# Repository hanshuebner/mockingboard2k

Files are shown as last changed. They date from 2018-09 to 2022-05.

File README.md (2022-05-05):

# mockingboard2k - Mockingboard compatible Apple II sound card

This Mockingboard clone uses SMD parts for all modern components.  The KiCAD
project was cloned from the Apple II 32-GPIO Card by Scott Alfter.

[Schematic](mockingboard2k.pdf)

Please make sure that you're using 6522A VIAs.  6522 chips often don't work
with the Phi2 generation circuit that is present on this board.

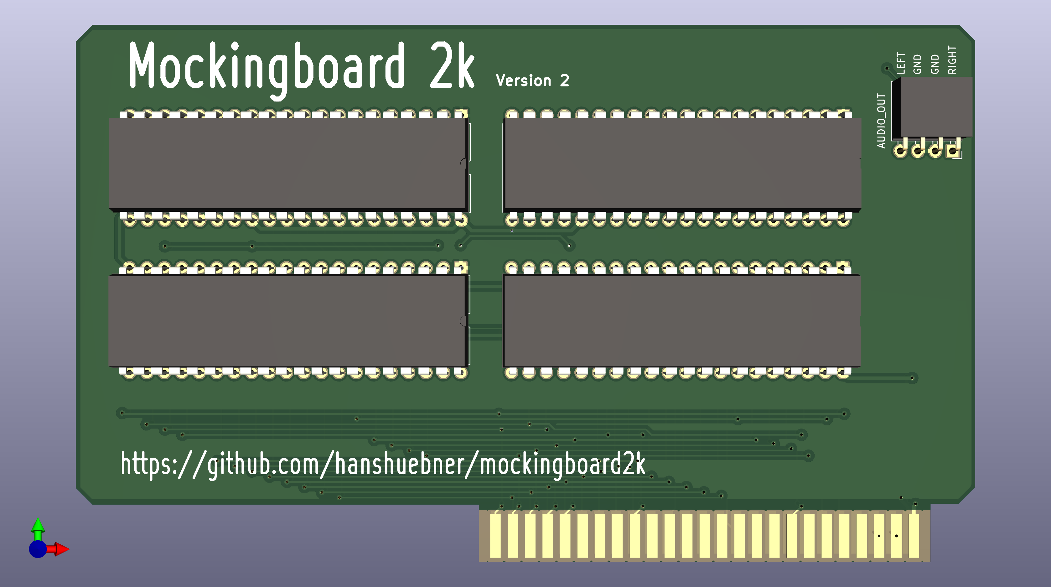
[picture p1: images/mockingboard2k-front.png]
PCB front PCB Front

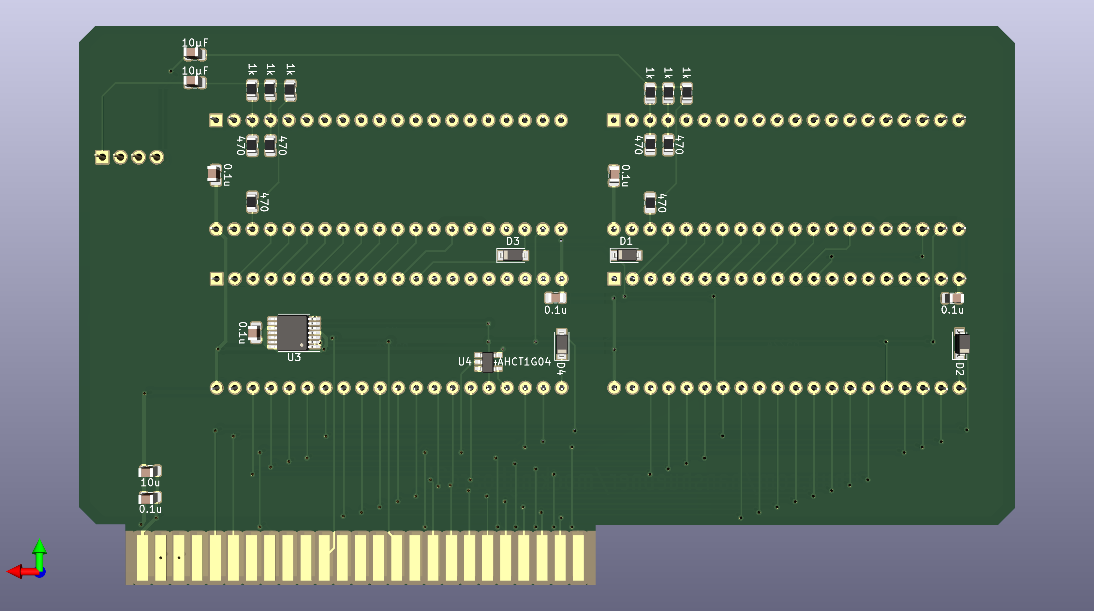
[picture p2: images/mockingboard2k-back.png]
PCB back PCB Back


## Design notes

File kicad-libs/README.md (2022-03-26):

KiCAD Library
=============

Components needed for my projects go here.  I'm starting with the proper
ANSI symbols for things like capacitors and resistors because KiCAD doesn't
provide them in its standard libraries.  Stuff needed for Apple II-related
projects is up next.

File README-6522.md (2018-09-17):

Apple II Dual-6522 GPIO Card
============================

This is a fairly straightforward implementation of a GPIO interface for the
Apple II, based on a pair of 6522 VIAs.  It is an extension of a design
published in c't Magazine in 1985, with the control lines on each 6522 also
brought out to header pins, the data bus buffered with a 74LS245, and the
ɸ2 signal needed by the 6522s generated by a pair of flip-flops in a 74LS74
in accordance with a technote published by Apple on the subject.  Most
components are surface-mount to reduce needed board area, though the 6522s
were kept in DIP form to allow use of either NOS (new old stock) 6522s from
whatever suppliers or the currently available WDC W65C22S.

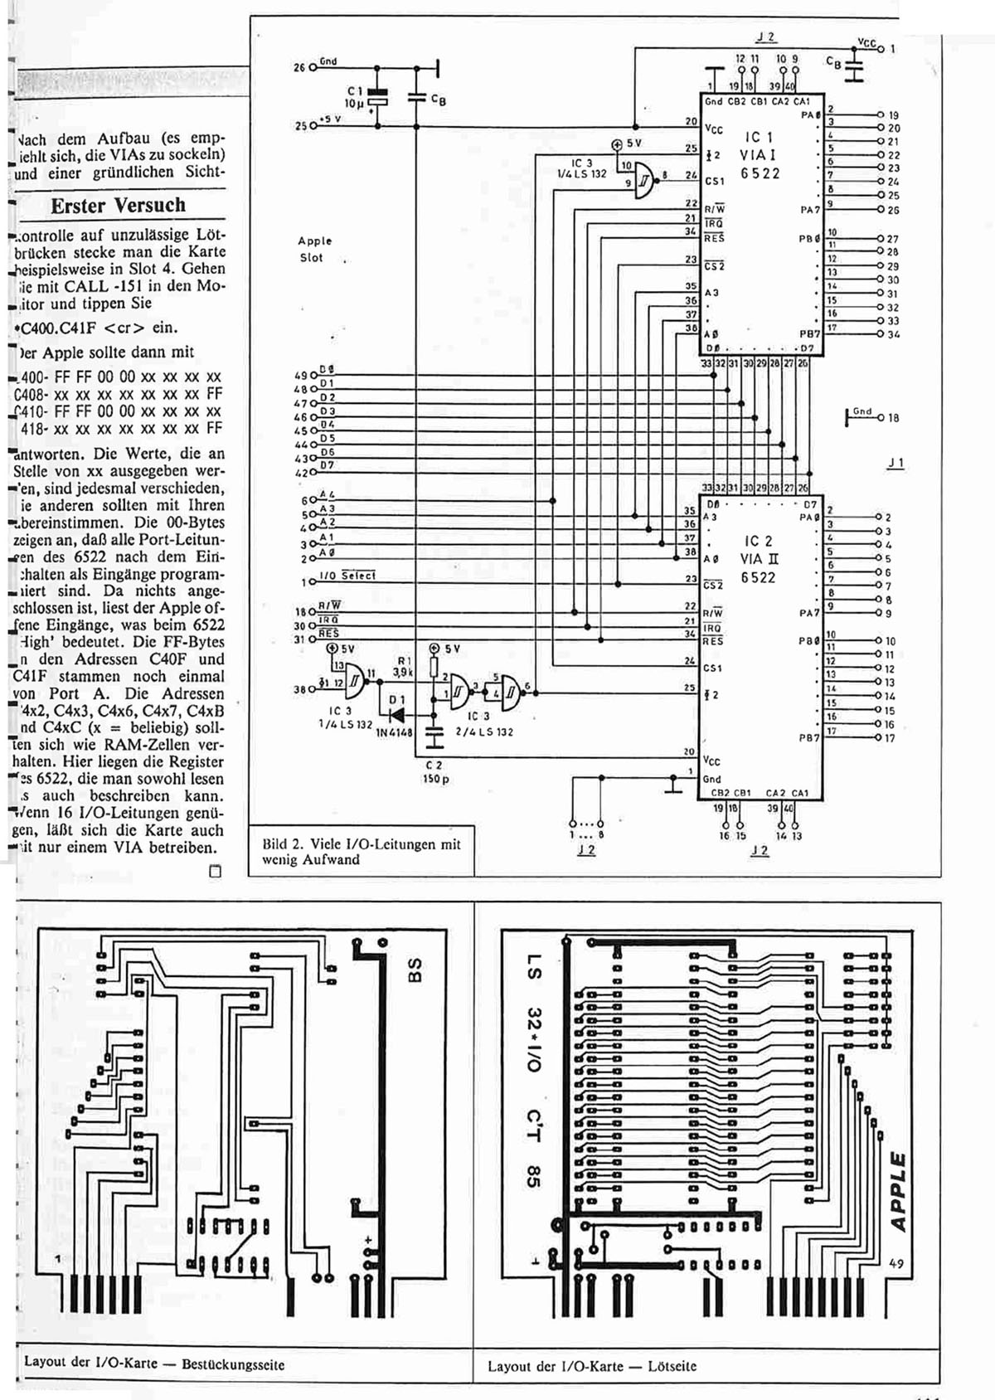
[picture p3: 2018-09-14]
docs/Apple2xVIA6522p2.jpg

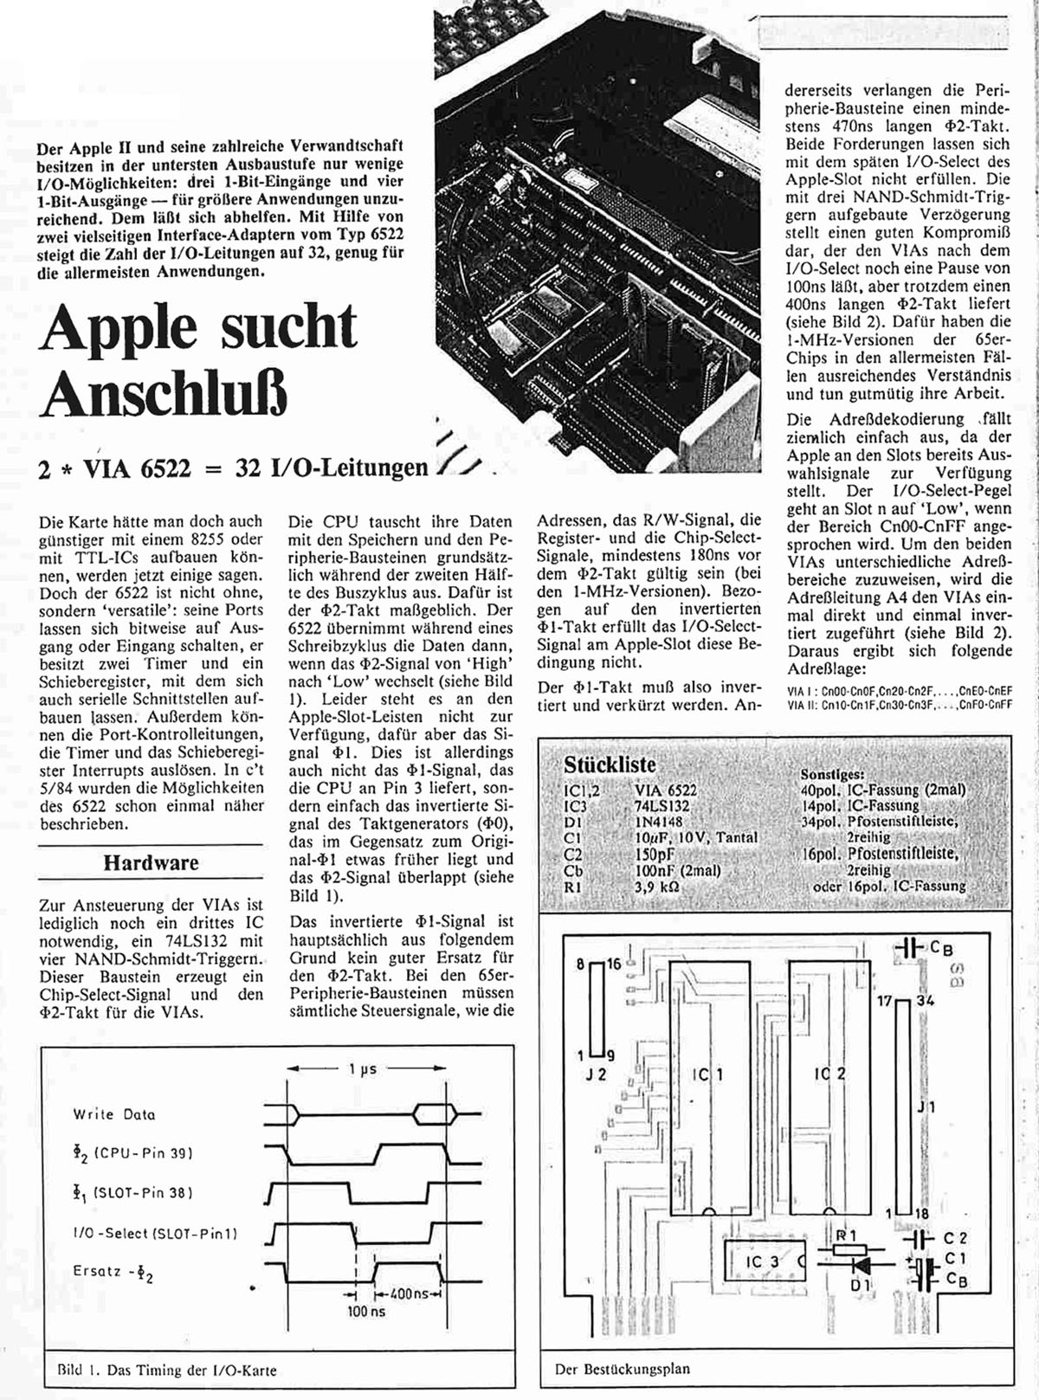
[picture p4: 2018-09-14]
docs/Apple2xVIA6522p1.jpg

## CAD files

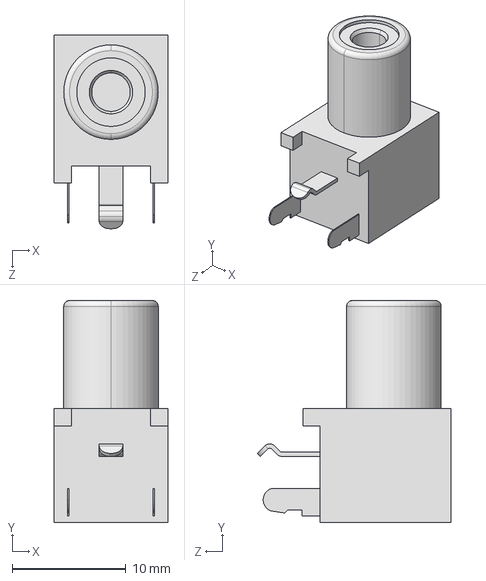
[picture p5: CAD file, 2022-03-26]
kicad-libs/models/pjran1x1_Series.stp
10.00 x 19.5 x 17.0 mm

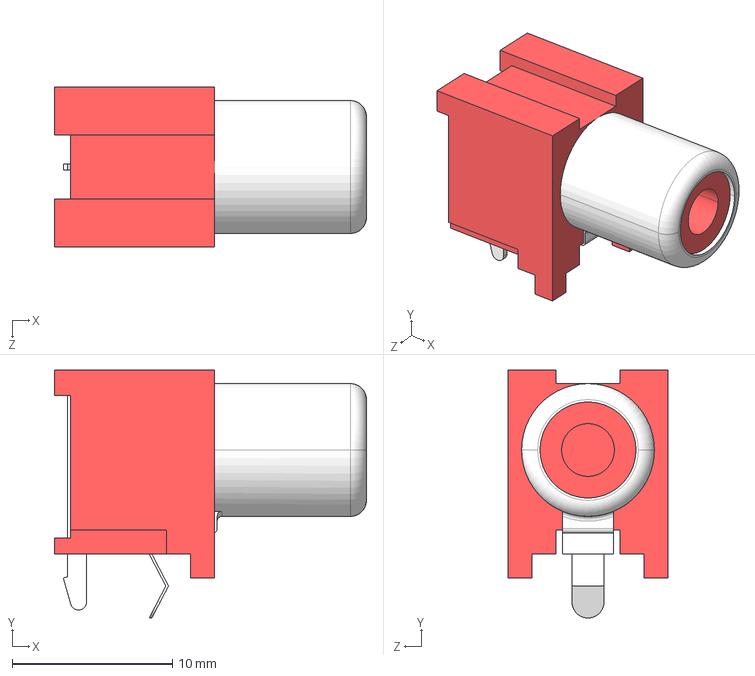
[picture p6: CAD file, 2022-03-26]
kicad-libs/models/CUI_RCJ-042.stp
19.5 x 15.5 x 10.0 mm

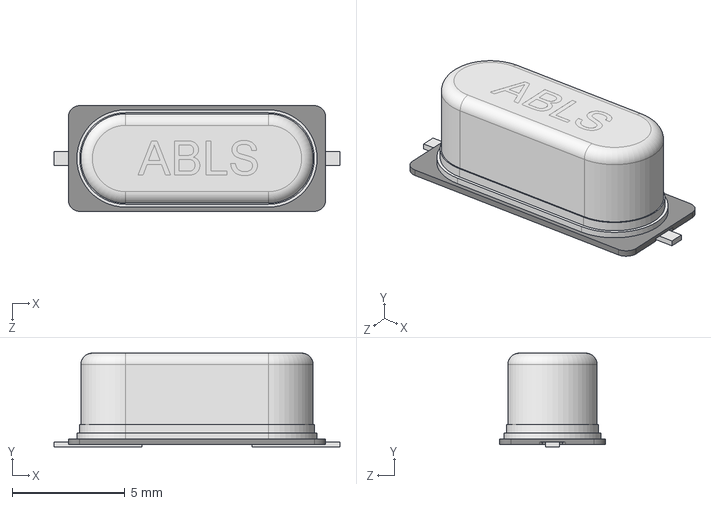
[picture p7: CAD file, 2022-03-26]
kicad-libs/models/hc49us.stp
12.7 x 4.17 x 4.70 mm

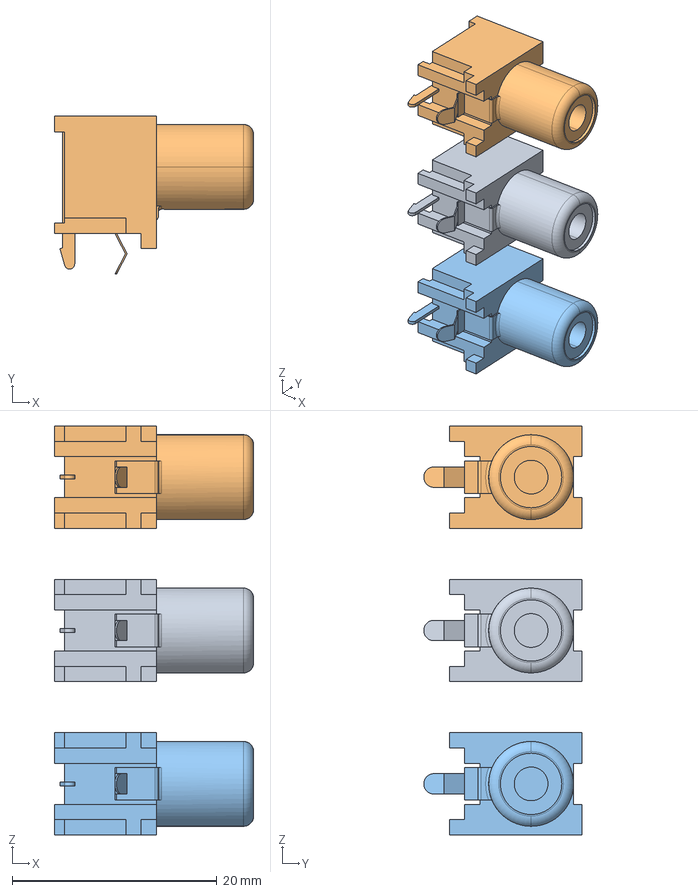
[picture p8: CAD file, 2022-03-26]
kicad-libs/models/temp-component.fcstd
19.5 x 15.5 x 40.0 mm
CUI_RCJ-041
CUI_RCJ-042
CUI_RCJ-043

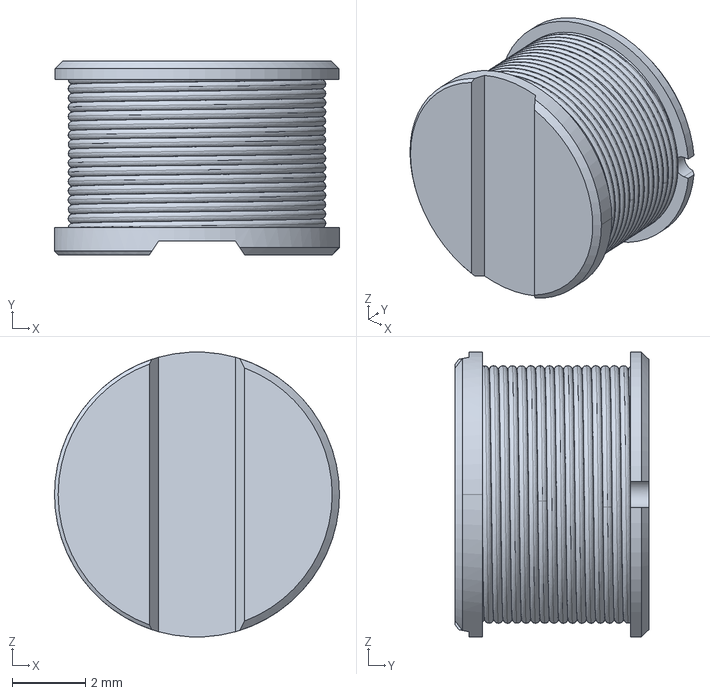
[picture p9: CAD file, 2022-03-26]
kicad-libs/models/sdr0805.stp
7.80 x 5.30 x 7.79 mm

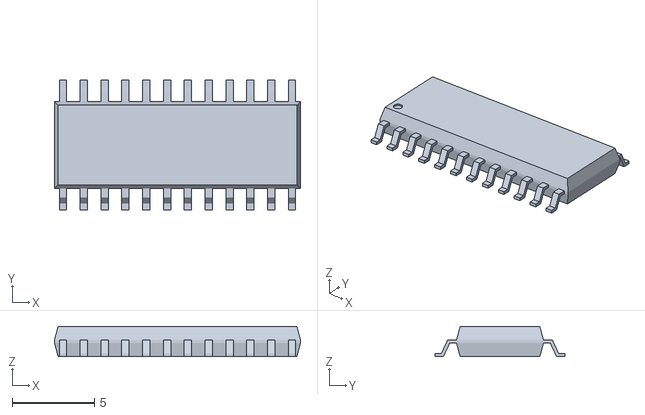
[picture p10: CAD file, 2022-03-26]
kicad-libs/models/SOP-24_15.0x5.3mm_P1.27mm.stl
15.0 x 7.90 x 1.85

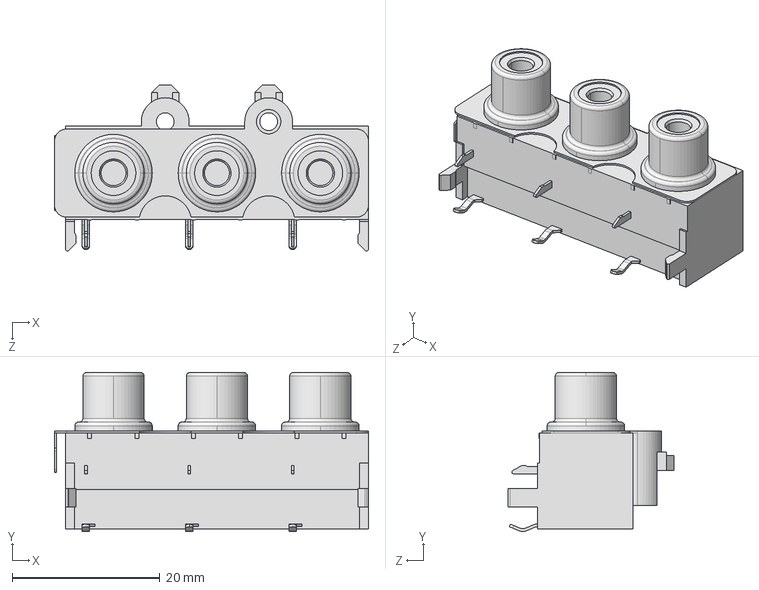
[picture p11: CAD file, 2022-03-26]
kicad-libs/models/pjras3x1s_series.stp
42.5 x 21.5 x 22.5 mm

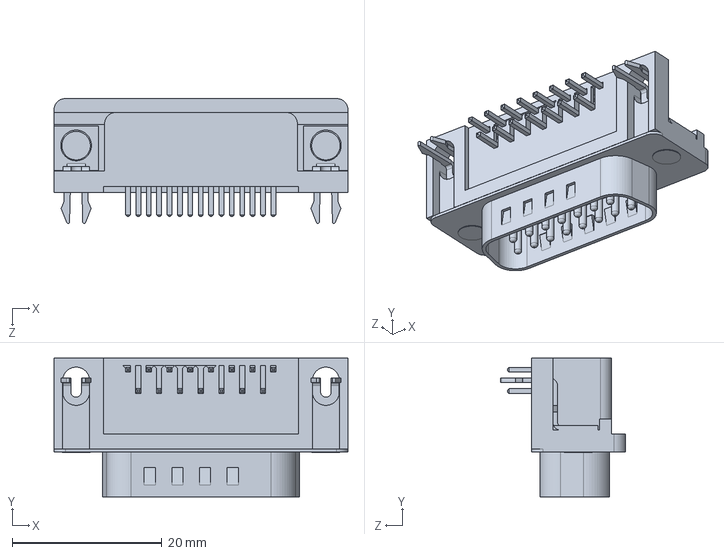
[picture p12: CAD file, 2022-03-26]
kicad-libs/models/db15m.stp
39.2 x 18.5 x 16.6 mm

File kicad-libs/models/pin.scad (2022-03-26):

// This module outputs bended pin
// _L - whole pin length
// _l - length of bottom part
// _H - whole pin height
// _th - pin thickness
// _a - bending angle
// _W - pin width
module pin(_L,_l,_H,_th,_a,_W)
{
	// Internal variables
    _d1 = _th*sin(_a) / (1-cos(_a));
    _d2 = (_th-_H)*cos(_a) / sin(_a);

	rotate([90,0,90])
    // Extrude the following polygon
	linear_extrude(height = _W, center = true, convexity = 10, twist = 0)
        polygon([[0,0],
                 [_l,0],
				 [_l+_d2,_H-_th],
				 [_L,_H-_th],
				 [_L,_H],
				 [_l+_d2-_d1,_H],
				 [_l-_d1,_th],
				 [0,_th]]);
}

// Example of usage
pin(2,1,1,0.2,115,0.5);

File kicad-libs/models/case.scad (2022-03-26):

// This module draws case
// _L - case length
// _W - case width
// _H - case height
// _ph - top point (vertical) of pin connection area
// _pt - pin thickness
// _atl - case angle top left,
// _atr - case angle top right,
// _atu - case angle top up
// _atd - case angle top down
// _abl - case angle bottom left,
// _abr - case angle bottom right,
// _abu - case angle bottom up
// _abd - case angle bottom down
// _n_x - notch X position relative to case corner
// _n_y - notch Y position relative to case corner
// _n_d - notch diameter
// _n_z - notch_depth
module case(_L,_W,_H,_ph,_pt,_atl,_atr,_atu,_atd,_abl,_abr,_abu,_abd, _n_x, _n_y, _n_d, _n_z)
{
    _tth = _H - _ph;
    _bth = _ph - _pt;
    _dtl = _tth * cos(_atl) / sin(_atl);
    _dtr = _tth * cos(_atr) / sin(_atr);
    _dtu = _tth * cos(_atu) / sin(_atu);
    _dtd = _tth * cos(_atd) / sin(_atd);
    _dbl = _bth * cos(_abl) / sin(_abl);
    _dbr = _bth * cos(_abr) / sin(_abr);
    _dbu = _bth * cos(_abu) / sin(_abu);
    _dbd = _bth * cos(_abd) / sin(_abd);
	// Make case with notch - difference between case and small cylinder
    difference()
    {
        // This is our case
        polyhedron(
            points = [
                // top points
                [ 0 + _dtl, 0 + _dtd, _H],
                [_L - _dtr, 0 + _dtd, _H],
                [_L - _dtr,_W - _dtu, _H],
                [ 0 + _dtl,_W - _dtu, _H],
                // middle top points
                [ 0, 0,_ph],
                [_L, 0,_ph],
                [_L,_W,_ph],
                [ 0,_W,_ph],
                // middle bottom points
                [ 0, 0,_ph - _pt],
                [_L, 0,_ph - _pt],
                [_L,_W,_ph - _pt],
                [ 0,_W,_ph - _pt],
                // bottom points
                [ 0 + _dbl, 0 + _dbd, 0],
                [_L - _dbr, 0 + _dbd, 0],
                [_L - _dbr,_W - _dbu, 0],
                [ 0 + _dbl,_W - _dbu, 0]
            ],
            faces = [
                // Top
                [ 0, 3, 2, 1],
                // Top sides
                [ 4, 0, 1, 5],
                [ 5, 1, 2, 6],
                [ 6, 2, 3, 7],
                [ 7, 3, 0, 4],
                // Middle sides
                [ 4, 5, 9, 8],
                [ 5, 6,10, 9],
                [ 6, 7,11,10],
                [ 7, 4, 8,11],
                // Bottom sides
                [12, 8, 9,13],
                [13, 9,10,14],
                [14,10,11,15],
                [15,11, 8,12],
                // Bottom
                [12,13,14,15]
            ]
        );
        // This is notch
        translate([_n_x,_n_y,_H])
            cylinder(r = _n_d/2, h = _n_z*2, center = true, $fn=10);
    }
}

// Example of usage
// case(10,5,1.5,0.7,0.3,80,80,80,80,45,45,45,45, 1,1,1);

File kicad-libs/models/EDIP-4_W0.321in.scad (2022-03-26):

// DIP Package Integrated Circuit
// 2017-11-03
// Mike Zemba

// Parametrically generates a Dual In-line Package (DIP)
// integrated circuit (IC).

// ----------
// PARAMETERS
// ----------

    nPinsIn = 4;
    
    icw  = 6.35; // Package - Width (Middle Section)
    ich1 = 0.254; // Package - Middle Section Height
    ich2 = 1.625; // Package - Top Section Height
    ich3 = 1.625; // Package - Bottom Section Height
    icec = 0.75;  // Package - End Cap Depth
    t1   = 0.711; // Package - Taper (Top)
    t2   = 0.711; // Package - Taper (Bottom)

    pitch = 5.08; // Pin Pitch

    pinw1 = 0.558; // Pin - Lower Section Width
    pinw2 = 1.320; // Pin - Upper Section Width
    pinh2 = 2.667; // Pin - Upper Section Height
    pinh1 = 2.540; // Pin - Lower Section Height
    pino  = 0.9; // Pin - Offset from Package
    pint  = 0.254; // Pin - Thickness
    
    nh = 0.5; // Notch Depth
    nd = 1.5; // Notch Diameter
    
    hh = 0.2; // Hole Depth
    hd = 1;   // Hole Diameter

// Round Up # Pins If Odd (Must Be Even)
nPins = 2*ceil(nPinsIn/2);

difference(){
    union(){
        for (i=[0:1:nPins/2-1])
            translate([pitch*i,0,0])
                ic_unit();
        translate([-pitch/2-icec/2,0,0])
            ic_end(icec,icw,t1,t2,ich1,ich2,ich3);
        translate([pitch/2+pitch*(nPins/2-1)+icec/2,0,0])
            mirror([1,0,0])
                ic_end(icec,icw,t1,t2,ich1,ich2,ich3);
    }
    union(){
        translate([-pitch/2,0,ich2+ich1/2-nh])
            color("DimGray") cylinder(d=nd,h=nh+1,$fn=30);
        translate([0,-icw/5,ich2+ich1/2-hh])
            color("DimGray") cylinder(d=hd,h=hh+1,$fn=30);
    }
}

module ic_unit(){
    ic_body(pitch,icw,t1,t2,ich1,ich2,ich3);
    translate([0,icw/2+pint/2+pino,pint/2])
        pin(pinw1,pinw2,pinh1,pinh2,pint,pino);
    translate([0,-icw/2-pint/2-pino,pint/2])
        mirror([0,1,0])
            pin(pinw1,pinw2,pinh1,pinh2,pint,pino);
}

module ic_end(pitch,icw,t1,t2,ich1,ich2,ich3){
    // Top Polyhedron Points
    endTopPoints = [
    [pitch/2, icw/2, ich1/2],             // 0   +x +y
    [-pitch/2, icw/2, ich1/2],            // 1   -x +y
    [pitch/2, -icw/2, ich1/2],            // 2   +x -y
    [-pitch/2, -icw/2, ich1/2],           // 3   -x -y
    [pitch/2, icw/2-t1, ich1/2+ich2],     // 4   +x +y
    //[-pitch/2, icw/2-t1, ich1/2+ich2],    // 5   -x +y
    [pitch/2, -icw/2+t1, ich1/2+ich2]];    // 6   +x -y
    //[-pitch/2, -icw/2+t1, ich1/2+ich2]];  // 7   -x -y

    // Bottom Polyhedron Points
    endBotPoints = [
    [pitch/2, icw/2, -ich1/2],            // 0   +x +y
    [-pitch/2, icw/2, -ich1/2],           // 1   -x +y
    [pitch/2, -icw/2, -ich1/2],           // 2   +x -y
    [-pitch/2, -icw/2, -ich1/2],          // 3   -x -y
    [pitch/2, icw/2-t2, -ich1/2-ich3],    // 4   +x +y
    //[-pitch/2, icw/2-t2, -ich1/2-ich3],   // 5   -x +y
    [pitch/2, -icw/2+t2, -ich1/2-ich3]];   // 6   +x -y
    //[-pitch/2, -icw/2+t2, -ich1/2-ich3]]; // 7   -x -y

    endTopFaces = [
      [2,0,1,3],  // bottom
      [5,4,0,2],  // front
      [3,1,4,5],  // top
      [4,1,0],  // right
      [5,2,3]]; // left
      
    endBotFaces = [
      [2,0,1,3],  // bottom
      [5,4,0,2],  // front
      [3,1,4,5],  // top
      [4,1,0],  // right
      [5,2,3]]; // left

    color("DimGray") cube([pitch,icw,ich1],center=true);
    color("DimGray") polyhedron(endTopPoints,endTopFaces);
    color("DimGray") polyhedron(endBotPoints,endBotFaces);
}

module ic_body(pitch,icw,t1,t2,ich1,ich2,ich3){
    // Top Polyhedron Points
    topPoints = [
    [pitch/2, icw/2, ich1/2],             // 0   +x +y
    [-pitch/2, icw/2, ich1/2],            // 1   -x +y
    [pitch/2, -icw/2, ich1/2],            // 2   +x -y
    [-pitch/2, -icw/2, ich1/2],           // 3   -x -y
    [pitch/2, icw/2-t1, ich1/2+ich2],     // 4   +x +y
    [-pitch/2, icw/2-t1, ich1/2+ich2],    // 5   -x +y
    [pitch/2, -icw/2+t1, ich1/2+ich2],    // 6   +x -y
    [-pitch/2, -icw/2+t1, ich1/2+ich2]];  // 7   -x -y

    // Bottom Polyhedron Points
    botPoints = [
    [pitch/2, icw/2, -ich1/2],            // 0   +x +y
    [-pitch/2, icw/2, -ich1/2],           // 1   -x +y
    [pitch/2, -icw/2, -ich1/2],           // 2   +x -y
    [-pitch/2, -icw/2, -ich1/2],          // 3   -x -y
    [pitch/2, icw/2-t2, -ich1/2-ich3],    // 4   +x +y
    [-pitch/2, icw/2-t2, -ich1/2-ich3],   // 5   -x +y
    [pitch/2, -icw/2+t2, -ich1/2-ich3],   // 6   +x -y
    [-pitch/2, -icw/2+t2, -ich1/2-ich3]]; // 7   -x -y

    topFaces = [
      [2,0,1,3],  // bottom
      [6,4,0,2],  // front
      [7,5,4,6],  // top
      [4,5,1,0],  // right
      [5,7,3,1],  // back
      [7,6,2,3]]; // left
      
    botFaces = [
      [2,0,1,3],  // bottom
      [6,4,0,2],  // front
      [7,5,4,6],  // top
      [4,5,1,0],  // right
      [5,7,3,1],  // back
      [7,6,2,3]]; // left

    color("DimGray") cube([pitch,icw,ich1],center=true);
    color("DimGray") polyhedron(topPoints,topFaces);
    color("DimGray") polyhedron(botPoints,botFaces);
}

module pin(pinw1,pinw2,pinh1,pinh2,pint,pino) {
    translate([-pinw2/2,-pint/2,-pinh2])
        color("Silver") cube([pinw2,pint,pinh2],center=false);
    translate([-pinw1/2,-pint/2,-pinh2-pinh1])
        color("Silver") cube([pinw1,pint,pinh1],center=false);
    translate([-pinw2/2,-pint/2-pino,-pint])  
        color("Silver") cube([pinw2,pino,pint]);
}

//translate([0,0,pinh1/2+pinh2/2])
//    cube([pinw2,pint,pinh2],center=true);

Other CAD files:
kicad-libs/models/CUI_RCJ-046.stp
kicad-libs/models/CUI_RCJ-045.stp
kicad-libs/models/SOP-24_15.0x5.3mm_P1.27mm.scad
kicad-libs/models/db15m.fcstd

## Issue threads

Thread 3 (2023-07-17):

Project status?

dlxmax, 2023-07-17:
Hi, I searched the net but couldn't find any references to this project, except for somebody selling pcb's on Ebay, which is how I learned about this.
Does it work? How are you handing the audio output? Are there any changes that need to be made?
Thanks for updating. Great work!

hanshuebner, 2023-07-17:
@dlxmax The card works well for me and for a couple of people that I've sent it to.  I don't currently have any plans to modify it - I have two RCA jacks connected to the outputs and use active speakers with that.  I don't think that adding an amp would make much sense, as active speakers are the norm nowadays.

dlxmax, 2023-07-17:
@hanshuebner Excellent. Thank you!

Closed 2023-07-18.

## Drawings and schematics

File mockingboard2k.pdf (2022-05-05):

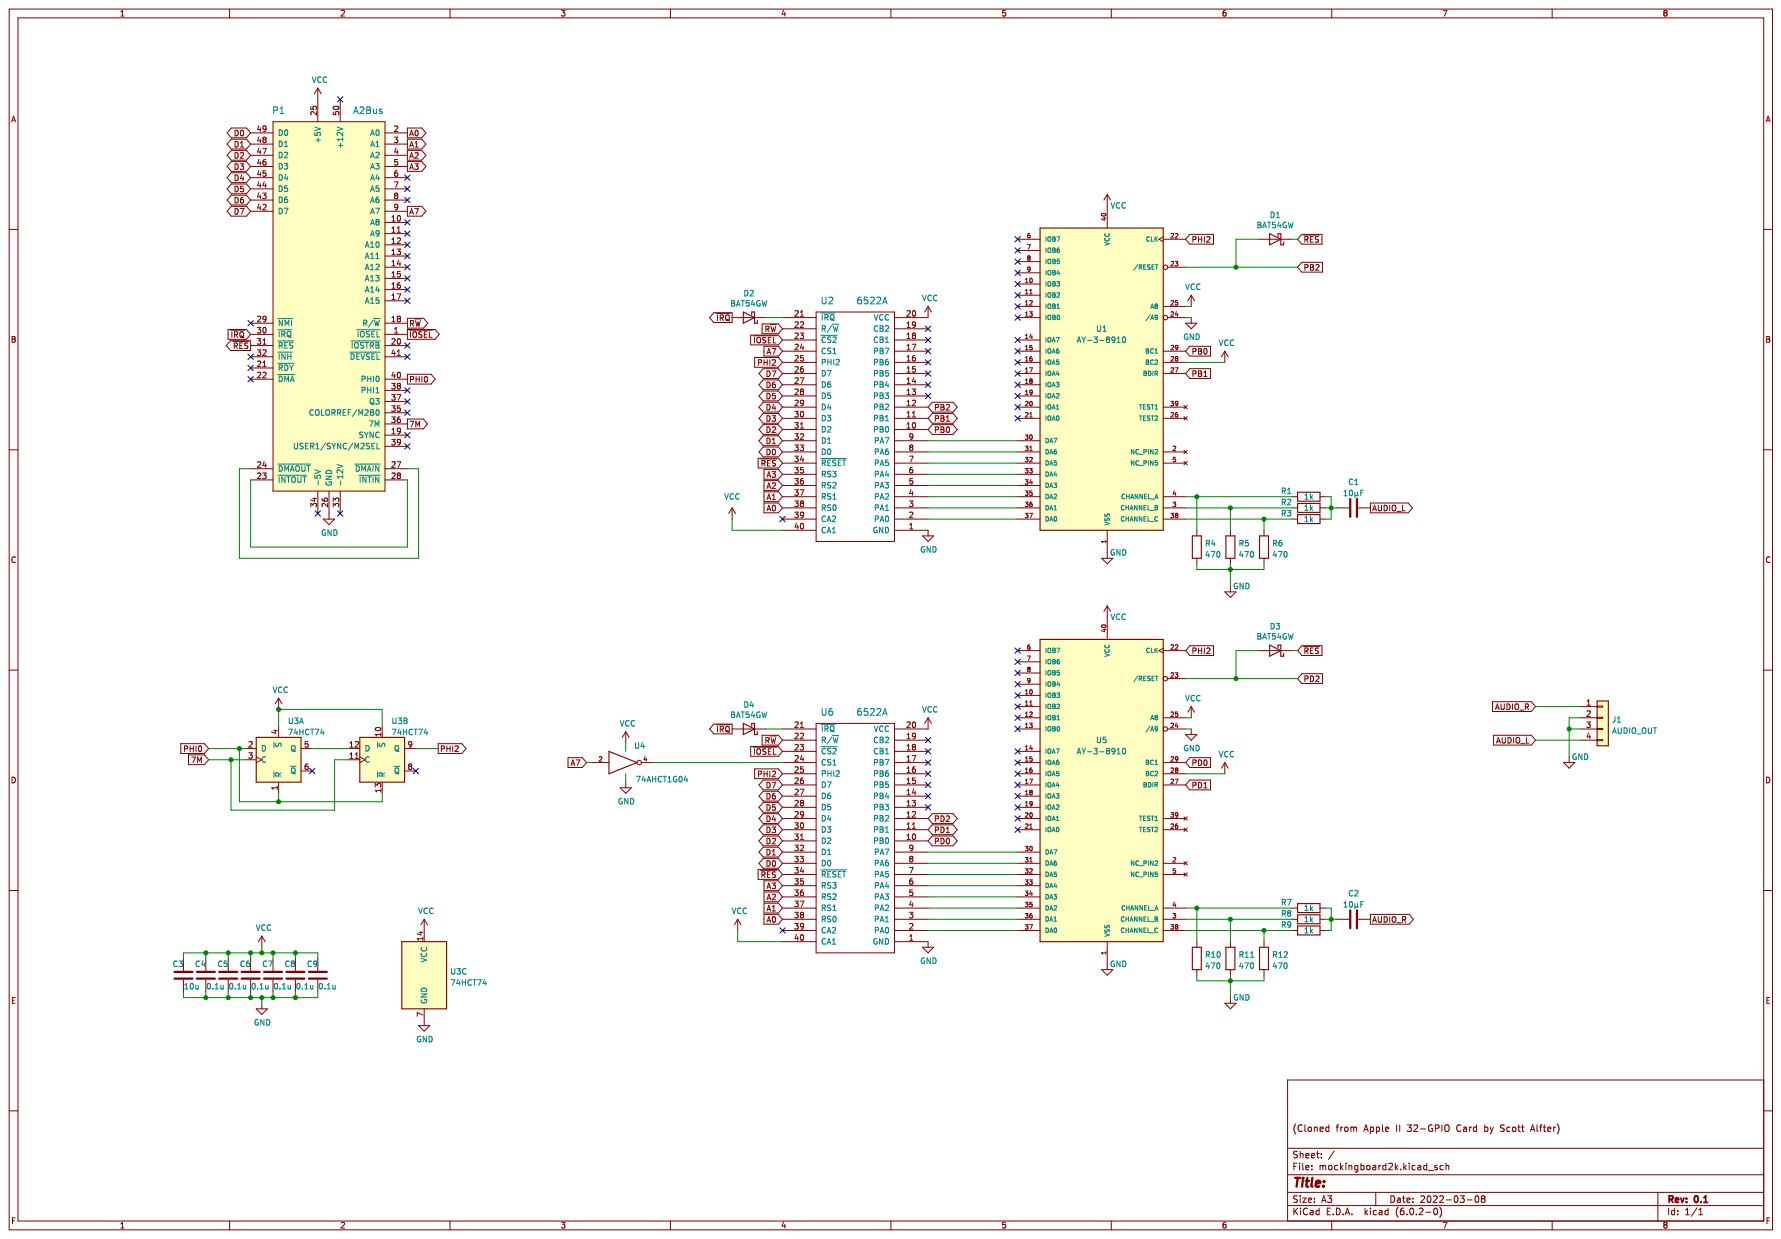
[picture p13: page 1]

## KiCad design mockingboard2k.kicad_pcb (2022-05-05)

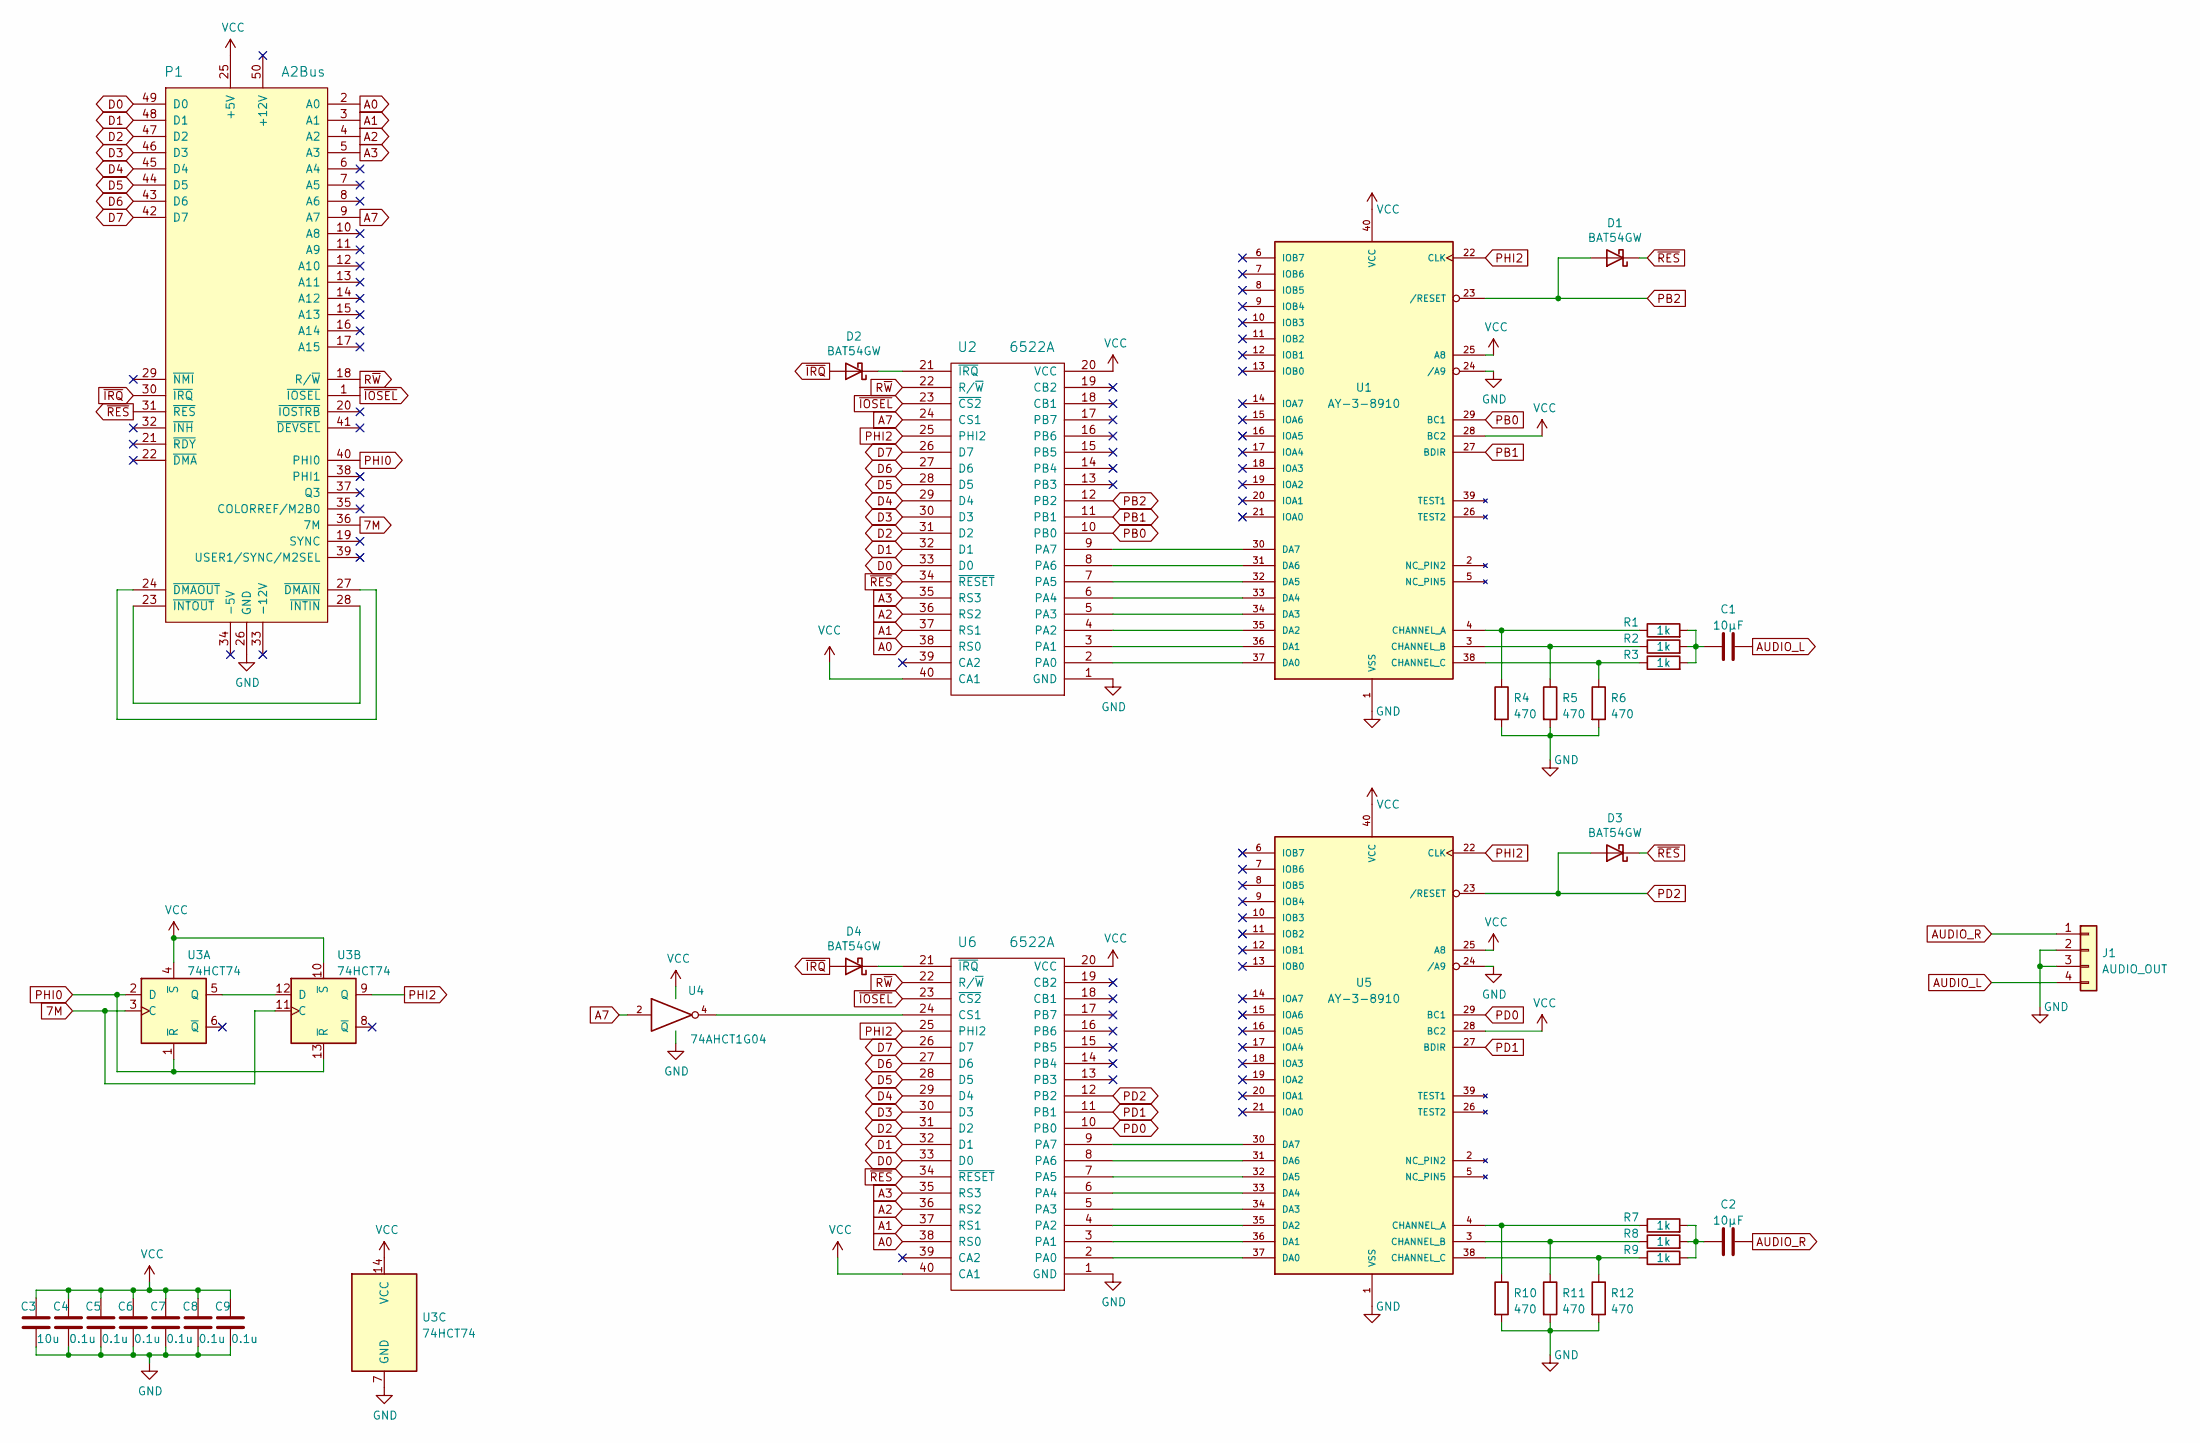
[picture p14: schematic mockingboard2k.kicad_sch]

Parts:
C1, C2: 10μF; C_0805_2012Metric; LCSC C2835555
C3: 10u; C_0805_2012Metric; LCSC C2830722
C4, C5, C6, C7, C8, C9: 0.1u; C_0805_2012Metric; LCSC C2830722
D1, D2, D3, D4: BAT54GW; D_SOD-123; Mfr PN BAT54GWJ; LCSC C77343
J1: AUDIO_OUT; PinSocket_1x04_P2.54mm_Horizontal
P1: A2Bus; Male_Card-Edge_50_pin__100_mil
R1, R2, R3, R7, R8, R9: 1k; R_0805_2012Metric; LCSC C325761
R4, R5, R6, R10, R11, R12: 470; R_0805_2012Metric; LCSC C269542
U1, U5: AY-3-8910; DIP-40_W15.24mm
U2, U6: 6522A; DIP-40_W15.24mm; Mfr PN W65C22S6TPG-14
U3: 74HCT74; TSSOP-14_4.4x5mm_P0.65mm; LCSC C8164
U4: 74AHCT1G04; 74AHCT1G04W5-7; LCSC C460498

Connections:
7M: P1.36 (7M), U3.3 (C), U3.11 (C)
A0: P1.2 (A0), U2.38 (RS0), U6.38 (RS0)
A1: P1.3 (A1), U2.37 (RS1), U6.37 (RS1)
A2: P1.4 (A2), U2.36 (RS2), U6.36 (RS2)
A3: P1.5 (A3), U2.35 (RS3), U6.35 (RS3)
A7: P1.9 (A7), U2.24 (CS1), U4.2
AUDIO_L: C1.2, J1.4
AUDIO_R: C2.2, J1.1
D0: P1.49 (D0), U2.33 (D0), U6.33 (D0)
D1: P1.48 (D1), U2.32 (D1), U6.32 (D1)
D2: P1.47 (D2), U2.31 (D2), U6.31 (D2)
D3: P1.46 (D3), U2.30 (D3), U6.30 (D3)
D4: P1.45 (D4), U2.29 (D4), U6.29 (D4)
D5: P1.44 (D5), U2.28 (D5), U6.28 (D5)
D6: P1.43 (D6), U2.27 (D6), U6.27 (D6)
D7: P1.42 (D7), U2.26 (D7), U6.26 (D7)
GND: C3.2, C4.2, C5.2, C6.2, C7.2, C8.2, C9.2, J1.2, J1.3, P1.26 (GND), R4.2, R5.2, R6.2, R10.2, R11.2, R12.2, U1.1 (VSS), U1.24 (/A9), U2.1 (GND), U3.7 (GND), U4.3 (GND), U5.1 (VSS), U5.24 (/A9), U6.1 (GND)
unnamed: C1.1, R1.2, R2.2, R3.2
unnamed: C2.1, R7.2, R8.2, R9.2
unnamed: D2.1 (K), U2.21 (~IRQ)
unnamed: D4.1 (K), U6.21 (~IRQ)
unnamed: P1.23 (~INTOUT), P1.28 (~INTIN)
unnamed: P1.24 (~DMAOUT), P1.27 (~DMAIN)
unnamed: R1.1, R4.1, U1.4 (CHANNEL_A)
unnamed: R2.1, R5.1, U1.3 (CHANNEL_B)
unnamed: R3.1, R6.1, U1.38 (CHANNEL_C)
unnamed: R7.1, R10.1, U5.4 (CHANNEL_A)
unnamed: R8.1, R11.1, U5.3 (CHANNEL_B)
unnamed: R9.1, R12.1, U5.38 (CHANNEL_C)
unnamed: U1.30 (DA7), U2.9 (PA7)
unnamed: U1.31 (DA6), U2.8 (PA6)
unnamed: U1.32 (DA5), U2.7 (PA5)
unnamed: U1.33 (DA4), U2.6 (PA4)
unnamed: U1.34 (DA3), U2.5 (PA3)
unnamed: U1.35 (DA2), U2.4 (PA2)
unnamed: U1.36 (DA1), U2.3 (PA1)
unnamed: U1.37 (DA0), U2.2 (PA0)
unnamed: U3.5 (Q), U3.12 (D)
unnamed: U4.4, U6.24 (CS1)
unnamed: U5.30 (DA7), U6.9 (PA7)
unnamed: U5.31 (DA6), U6.8 (PA6)
unnamed: U5.32 (DA5), U6.7 (PA5)
unnamed: U5.33 (DA4), U6.6 (PA4)
unnamed: U5.34 (DA3), U6.5 (PA3)
unnamed: U5.35 (DA2), U6.4 (PA2)
unnamed: U5.36 (DA1), U6.3 (PA1)
unnamed: U5.37 (DA0), U6.2 (PA0)
PB0: U1.29 (BC1), U2.10 (PB0)
PB1: U1.27 (BDIR), U2.11 (PB1)
PB2: D1.2 (A), U1.23 (/RESET), U2.12 (PB2)
PD0: U5.29 (BC1), U6.10 (PB0)
PD1: U5.27 (BDIR), U6.11 (PB1)
PD2: D3.2 (A), U5.23 (/RESET), U6.12 (PB2)
PHI0: P1.40 (PHI0), U3.1 (~R), U3.2 (D), U3.13 (~R)
PHI2: U1.22 (CLK), U2.25 (PHI2), U3.9 (Q), U5.22 (CLK), U6.25 (PHI2)
R~W: P1.18 (R/~W), U2.22 (R/~W), U6.22 (R/~W)
VCC: C3.1, C4.1, C5.1, C6.1, C7.1, C8.1, C9.1, P1.25 (+5V), U1.25 (A8), U1.28 (BC2), U1.40 (VCC), U2.20 (VCC), U2.40 (CA1), U3.4 (~S), U3.10 (~S), U3.14 (VCC), U4.5 (VCC), U5.25 (A8), U5.28 (BC2), U5.40 (VCC), U6.20 (VCC), U6.40 (CA1)
~IOSEL: P1.1 (~IOSEL), U2.23 (~CS2), U6.23 (~CS2)
~IRQ: D2.2 (A), D4.2 (A), P1.30 (~IRQ)
~RES: D1.1 (K), D3.1 (K), P1.31 (~RES), U2.34 (~RESET), U6.34 (~RESET)

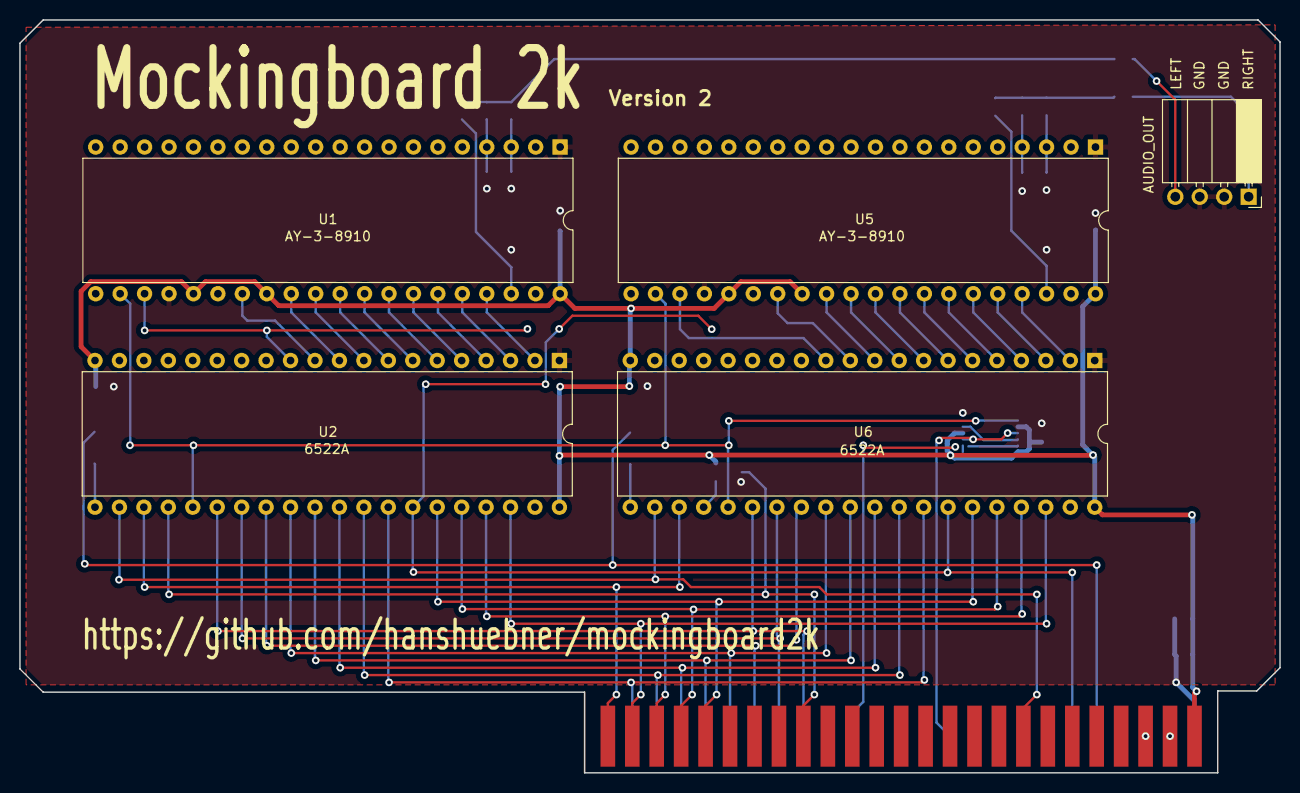
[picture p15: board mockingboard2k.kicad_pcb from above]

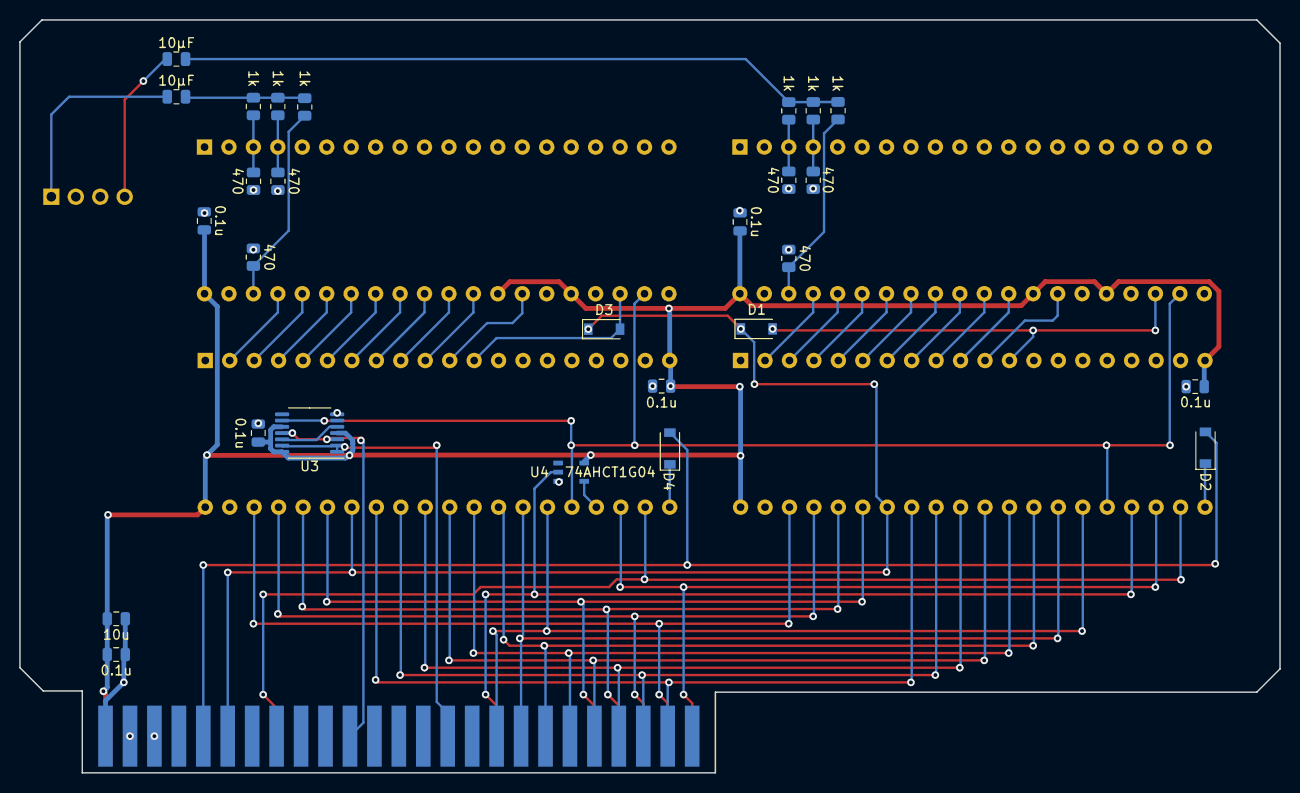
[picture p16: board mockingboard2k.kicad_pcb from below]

Board: 2 copper layers, 130.9 x 78.2 mm, 33 parts (27 on the bottom side), 60 nets.

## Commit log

2018-09-14 more routing
    [6522.kicad_pcb]
2018-09-16 routing complete
    [6522.kicad_pcb, 6522.sch]
2018-09-16 shrink card a bit
    [6522.kicad_pcb]
2018-09-17 trim 150 mils off edge connector, generate gerbers
    [6522-B.Cu.gbl, 6522-B.Mask.gbs, 6522-B.Paste.gbp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]
2018-09-17 add documentation
    [6522-B.Cu.gbl, 6522-B.Mask.gbs, 6522-B.Paste.gbp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]
2018-09-17 add Schottky diodes on IRQ outputs for W65C22S
    [6522-B.Cu.gbl, 6522-B.Mask.gbs, 6522-B.Paste.gbp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]
2018-09-17 add a PDF of the schematic
2018-09-18 edge connector revised
    [6522-B.Cu.gbl, 6522-B.Mask.gbs, 6522-B.Paste.gbp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]
2022-03-26 Mockingboard with delay-based Phi2
    [6522.csv, 6522.kicad_pcb, 6522.kicad_sch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]
2022-03-26 All-SMD version
    [6522.csv, 6522.kicad_pcb, 6522.kicad_sch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]
2022-03-26 Internalizing libs
    [mockingboard2k.kicad_pcb, mockingboard2k.kicad_sch]
2022-03-26 Add libs
    [CUI_RCJ-042.stp, CUI_RCJ-045.stp, CUI_RCJ-046.stp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]
2022-03-26 Version 1 ordered at JLCPCB
    [6522-B.Cu.gbl, 6522-B.Mask.gbs, 6522-B.Paste.gbp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]
2022-05-05 Fixes to 3D model, README update, gerbers update
    [mockingboard2k-B_Cu.gbl, mockingboard2k-B_Mask.gbs, mockingboard2k-B_Paste.gbp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]
2022-05-05 Add schematic PDF

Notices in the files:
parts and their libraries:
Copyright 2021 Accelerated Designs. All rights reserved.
